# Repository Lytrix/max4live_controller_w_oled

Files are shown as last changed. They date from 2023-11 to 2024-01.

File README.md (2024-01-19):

# Max4Live Magnetic Encoder controller with oled screen 

This repository contain the files to be able to create a Max4live 4 controller with Oled as a 5HP Eurorack module to control your VST plugins.

This setup can easily be extended to a 4 units by using jumper cables on the same pcb together with the headers on the boards to maximize a 5 panel order from jlcpcb.

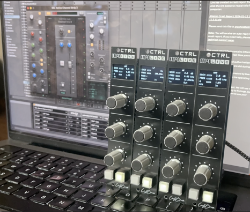
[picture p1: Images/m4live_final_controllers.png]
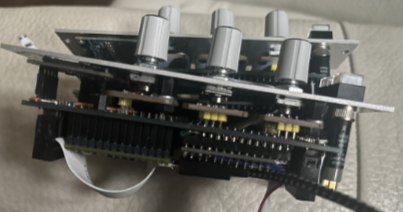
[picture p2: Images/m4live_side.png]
 

### How to install & use ###

1. Download this repo
2. Open the Arduino code and upload to the Teensy
3. Copy the `Max4Live Controller & Hub` folder to `/Music/Ableton/User Library/Presets/Audio Effects`
4. Open Ableton and place the `Max4live Serial Hub OSC.amxd` to the master channel and select your Teensy device.
5. Place `Max4live Controller OSC.amxd` on to the track you want to control
6. Select the VST device in the pull down menu which you want to control
7. Select the parameters for each potentiometer and button row.

### History ###

After using excelent Eurorack Droid system and having created my own Launchpad type solution on it, I wanted to have more hands on controllers also for my VST plugins within Ableton.

I really like the SSL suite of EQ's so I first looked at the UC1, As it was too big to fit in my small studio, I decided to build my own eurorack version to fit into my controller case with visual feedback to limit having to look at the DAW screen when adjusting EQ. 

#### MIDI? ####
I discovered early on the 127 midi steps were not fine grained enough.
Even using the pitchbend range or using MSB/LSB (sending on CC1 + CC 32) were often with issues still:
1. Still quite noisy with an analog encoder so hard to dail in precise values
2. Ableton could not set a parameter as 14bit midi 

So after some experimentation I decided to go with using an 3 euro AS5600 magnetic encoder and a cheap 0.75 Euro EC11 encoder to get a noise free 12bit 4096 step resolution which was precise enough to dail precise frequencies using this video as an example:
https://www.youtube.com/watch?v=1UmqNF65rck

This worked surpisingly well and is a great hack!

#### Breadboard tests and hacking the potentiometer to work with the magnetic encoder ####

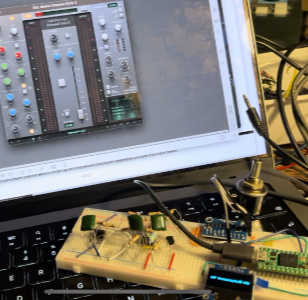
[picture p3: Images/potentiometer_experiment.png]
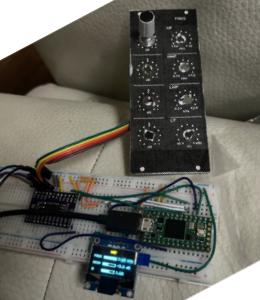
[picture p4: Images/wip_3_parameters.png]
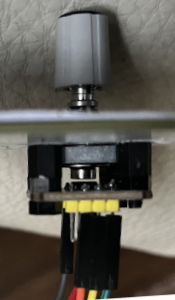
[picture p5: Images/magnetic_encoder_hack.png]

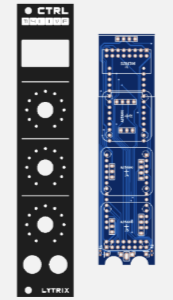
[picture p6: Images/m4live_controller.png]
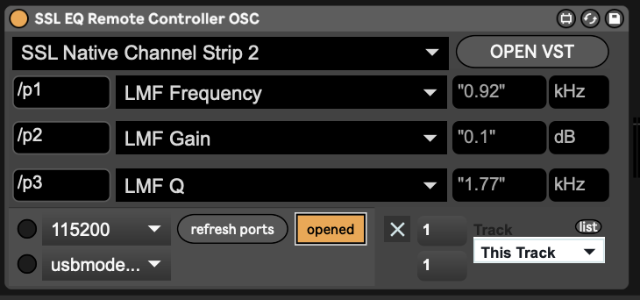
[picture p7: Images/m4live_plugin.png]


#### SYNC mouse and controller input ####
The next challenge was to ensure the encoder did not switch back to 0 halfway if the parameter changed via mouse input or when the parameter type changed. 
The solution was to set the offset of the magnetic encoder chip when the value changed externally. That way the encoder is always in sync before it adjusts it's value.

I coded a piece of logic to ensure whenever the value of the encoder is outside of +-2 numbers, MaxMSP sends an offset value update to the Teensy. 
The encoder is only allowed to change the values when the values of the VST parameter and the AS5600 offset are the same.

Th next challenge was to ensure the value was updated before the encoder could output any values. Here I got a lot of race condition issues, and it took me a week before I could tackle this. 

#### Controller & Display updates ####
For all functions I use lists to iterate over all changed values which are updated and also to set each of the AS5600 controllers and OSC adresses within different functions. This makes the code more DRY and makes it easier to add more parameters.

I created one function to gather all values to be displayed which loops in the main loop of the Arduino code.
I also created one function to set all updates from the encoders
And created one function to parse to each specific OSC address recieving part. 

### Parts list ###
- 1 Teensy 4.0 with headers
- 4-16 [AS5600 magnetic angle sensors](https://www.tinytronics.nl/shop/en/sensors/magnetic-field/as5600-magnetic-angle-sensor-encoder-module)
- 4-16 [EC11 rotary encoders](https://www.tinytronics.nl/shop/en/switches/manual-switches/rotary-encoders/rotary-encoder-ec11-20mm)
- 1-4 [25mm wide SSD1306 Oled Screens](https://www.ebay.com/itm/145136236774), or [Gadgetbouw.nl](https://www.gadgetbouw.nl/shop/0-96inch-128x64-i2c-oled-scherm-ssd1306-wit-of-blauw/) Check if they are really 25mm in width visible by the mounting holes being directly to the end of the pcb on both sides. Most cheap SSD1306 Oleds are 27mm.
- 1-5 PCB boards from jlcpcb
- 1-5 Alu front panels from jlcpcb
- Header pins and sockets
- [M3 nylon spacers 6mm](https://www.amazon.nl/dp/B07CG7F2YL?psc=1&ref=ppx_yo2ov_dt_b_product_details)
- [M3 nylon nuts](https://www.amazon.nl/dp/B07CG4C5QY?psc=1&ref=ppx_yo2ov_dt_b_product_details)
- 1 Superglue for mounting magnets and spacers
- 2-8 pushbuttons [EAO](https://www.techniekwebshop.nl/eao-benelux-serie-19-drukknop-9x9-puls-1m-verlicht-verkoop-per-1-x-1-stuk-19-451-035-7011339-type-knop-hoog-kleur-knop-zonder-toetsenp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) or cheaper 9.2mm types from [Ebay](https://www.ebay.com/itm/154221529860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) 

## Software ##

The software side consists on 2 pieces of code. One for the Teensy and one for Max4live.

I tested first a simple setup with using the standard serial ASCII communication, but found it quite fiddly to ensure to retrieve each different piece of information being send.
The [Open Sound Control (OSC)](https://opensoundcontrol.stanford.edu/spec-1_0.html) addressing structure felt like a much more robust way to send information back and forth, but unfortunately the OSC library from [CNMAT](https://github.com/CNMAT/OSC) did not work properly any more in the current MaxMSP and via serial (instead of network port). After a lot of research I finally found a good working library to make this work on the Teensy with MaxMSP (jey!):
https://github.com/thomasfredericks/MicroOsc

### Research documentation ###

Max4Live using more than 1 instance fix: add r --- to create random unique numbers
https://cycling74.com/forums/multiple-max4live-instances

Serial input Teensy to MaxMSP
https://www.youtube.com/watch?v=6bT3G4Mep7E

Serial output MaxMSP to Teensy
https://www.youtube.com/watch?v=68L-WHh3Ows

Button switch using internal pull up:
https://www.pjrc.com/teensy/td_digital.html  

MaxMSP scaling log
https://cycling74.com/forums/vst-plugin-parameter-scaling-problem

Dynamically load bpatchers:
https://cycling74.com/forums/dynamically-created-sub-patchersbpatches

Dummy virtual Serial
https://arduino.stackexchange.com/questions/9857/can-i-make-the-arduino-ignore-serial-print

Best example with many displays
https://www.youtube.com/watch?v=XFh9ZhL0jhE

Control Surface library struggle
https://github.com/tttapa/Control-Surface/issues/286

Good example to start with, also using 4 displays and using MCU:
https://projecthub.arduino.cc/criusdigitalstudio/diy-usb-midi-daw-controller-ecdcf6

good example of display fader
https://github.com/yilmazyurdakul/ArduinoOledMidiController
https://github.com/yilmazyurdakul/ArduinoOledMidiController/blob/main/ArduinoFile.ino

4 rotary encoders with midi control
http://little-scale.blogspot.com/2017/04/teensy-36-basicsusing-rotary-encoders.html

2 displays
https://www.brainy-bits.com/post/two-is-better-than-one-how-to-connect-two-spi-oled-displays

4 displays with Arduino
https://www.youtube.com/watch?v=MO6hbQcX8fE

4 displays and 4 encoders with visuals
https://projecthub.arduino.cc/yilmazyurdakul/arduino-midi-controller-with-encoder-oled-display-eeprom-311960

### Libraries ###
display https://www.pjrc.com/teensy/td_libs_SSD1306.html
encoder https://www.pjrc.com/teensy/td_libs_Encoder.html
endless potentiometer: https://github.com/juanlittledevil/EndlessPotentiometer
noise reducer analog signal: https://github.com/dxinteractive/ResponsiveAnalogRead

scroll text example:
https://stackoverflow.com/questions/40564050/scroll-long-text-on-oled-display

midi https://github.com/tttapa/Control-Surface

## LCD suggestions ###
http://midibox.org/forums/topic/29225-modul-box-ng-v2/?do=findComment&comment=199453

Oled display <25mm height
https://www.winstar.com.tw/products/oled-module/graphic-oled-display/sh1106-oled.html

multiplexer met tutorial (zie ook youtube filmpje)
https://www.tinytronics.nl/shop/nl/communicatie-en-signalen/io-converters/i2c-multiplexer-tca9548a

128 pulse encoder (too expensive)
https://nl.mouser.com/datasheet/2/54/ace-777357.pdf

1024 to 256 midi values with 10 bit nano:
https://forum.arduino.cc/t/potentiometer-send-midi-cc/142766/7

analog potentiometer Kore2:
https://hackaday.io/project/171841-driveralgorithm-for-360-deg-endless-potentiometer
with: https://nl.mouser.com/ProductDetail/Alpha-Taiwan/RV112FF-40B3N22F0B10K?qs=Znm5pLBrcAJwOGngbhkPgg%3D%3D

more examples:
https://diyelectromusic.wordpress.com/2021/09/28/arduino-midi-rotary-encoder-controller/

magnetic encoder:
https://curiousscientist.tech/blog/as5600-magnetic-position-encoder

working magnetic encoder example
https://www.youtube.com/watch?v=1UmqNF65rck

Bourns dail 20 turn
https://www.zendamateur-marktplaats.nl/componenten/componenten-anders/bourns-dial-model-h-46-36496.html

potential bigger potentiometer:
https://www.gear4music.com/Guitar-and-Bass/Emerson-Custom-CTS-250K-Short-Split-Shaft-Pro-Potentiometer/1GAA

Encoder example fast/slow relative unsigned bit:
https://remotify.io/community/question/absolute-14-bit

OSC
https://github.com/CNMAT/OSC/blob/master/examples/SerialOscuinowithMessages/SerialOscuinowithMessages.ino
https://www.ableton.com/en/packs/connection-kit/
https://github.com/thomasfredericks/MicroOsc

https://forum.arduino.cc/t/slipserial-and-osc-but-generally-reading-serial-across-loop-s/563369

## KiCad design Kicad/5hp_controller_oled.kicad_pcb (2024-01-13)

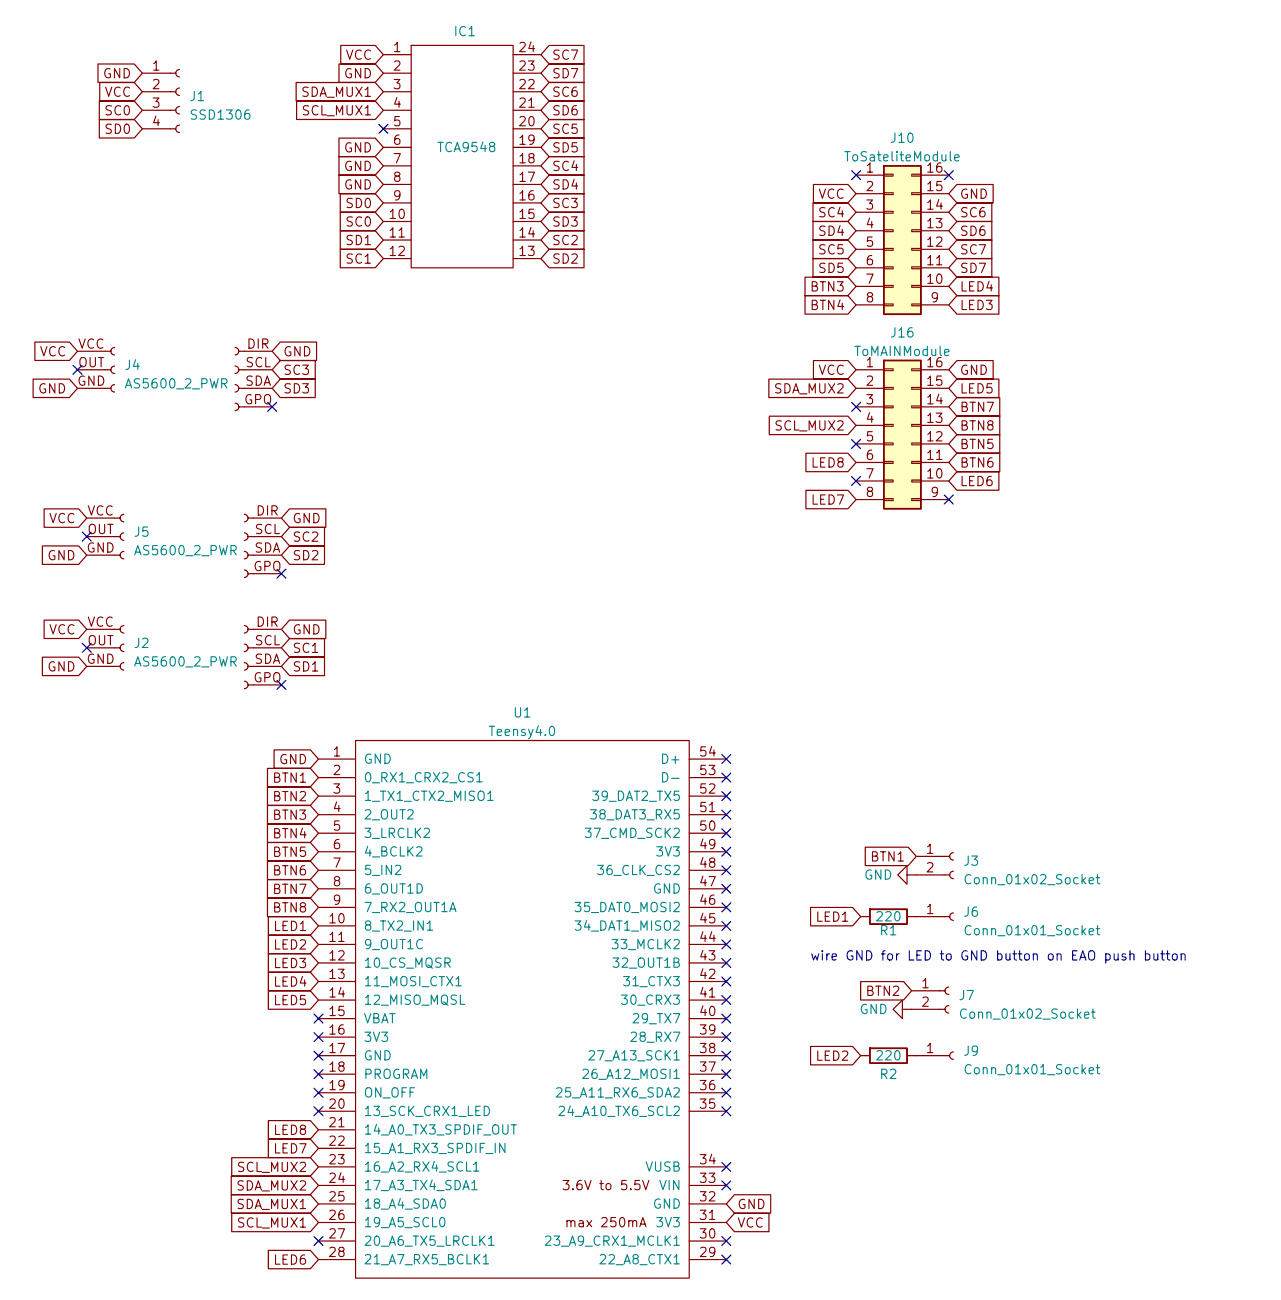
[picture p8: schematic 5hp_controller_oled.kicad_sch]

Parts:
IC1: TCA9548; DIP-24_W9.xx mm_Socket
J1: SSD1306; 128x64OLED_25mm
J2, J4, J5: AS5600_2_PWR; AS5600
J3, J7: Conn_01x02_Socket; PinHeader_1x02_P2.54mm_Vertical
J6, J9: Conn_01x01_Socket; PinHeader_1x01_P2.54mm_Vertical
J10: ToSateliteModule; PinSocket_2x08_P2.54mm_Vertical
J16: ToMAINModule; PinSocket_2x08_P2.54mm_Vertical
R1, R2: 220; R_0603_1608Metric_Pad0.98x0.95mm_HandSolder
U1: Teensy4.0; Teensy40_SMT

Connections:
BTN1: J3.1, U1.2 (0_RX1_CRX2_CS1)
BTN2: J7.1, U1.3 (1_TX1_CTX2_MISO1)
BTN3: J10.7, U1.4 (2_OUT2)
BTN4: J10.8, U1.5 (3_LRCLK2)
BTN5: J16.12, U1.6 (4_BCLK2)
BTN6: J16.11, U1.7 (5_IN2)
BTN7: J16.14, U1.8 (6_OUT1D)
BTN8: J16.13, U1.9 (7_RX2_OUT1A)
GND: IC1.2 (GND), IC1.6 (A0), IC1.7 (A1), IC1.8 (A2), J1.1, J2.DIR (Pin_4), J2.GND (Pin_3), J3.2, J4.DIR (Pin_4), J4.GND (Pin_3), J5.DIR (Pin_4), J5.GND (Pin_3), J7.2, J10.15, J16.16, U1.1 (GND), U1.32 (GND)
LED1: R1.2, U1.10 (8_TX2_IN1)
LED2: R2.2, U1.11 (9_OUT1C)
LED3: J10.9, U1.12 (10_CS_MQSR)
LED4: J10.10, U1.13 (11_MOSI_CTX1)
LED5: J16.15, U1.14 (12_MISO_MQSL)
LED6: J16.10, U1.28 (21_A7_RX5_BCLK1)
LED7: J16.8, U1.22 (15_A1_RX3_SPDIF_IN)
LED8: J16.6, U1.21 (14_A0_TX3_SPDIF_OUT)
unnamed: J6.1, R1.1
unnamed: J9.1, R2.1
SC0: IC1.10 (SC0), J1.3
SC1: IC1.12 (SC1), J2.SCL (Pin_5)
SC2: IC1.14 (SC2), J5.SCL (Pin_5)
SC3: IC1.16 (SC3), J4.SCL (Pin_5)
SC4: IC1.18 (SC4), J10.3
SC5: IC1.20 (SC5), J10.5
SC6: IC1.22 (SC6), J10.14
SC7: IC1.24 (SC7), J10.12
SCL_MUX1: IC1.4 (SCL), U1.26 (19_A5_SCL0)
SCL_MUX2: J16.4, U1.23 (16_A2_RX4_SCL1)
SD0: IC1.9 (SD0), J1.4
SD1: IC1.11 (SD1), J2.SDA (Pin_6)
SD2: IC1.13 (SD2), J5.SDA (Pin_6)
SD3: IC1.15 (SD3), J4.SDA (Pin_6)
SD4: IC1.17 (SD4), J10.4
SD5: IC1.19 (SD5), J10.6
SD6: IC1.21 (SD6), J10.13
SD7: IC1.23 (SD7), J10.11
SDA_MUX1: IC1.3 (SDA), U1.25 (18_A4_SDA0)
SDA_MUX2: J16.2, U1.24 (17_A3_TX4_SDA1)
VCC: IC1.1 (VCC), J1.2, J2.VCC (Pin_1), J4.VCC (Pin_1), J5.VCC (Pin_1), J10.2, J16.1, U1.31 (3V3)

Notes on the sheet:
wire GND for LED to GND button on EAO push button

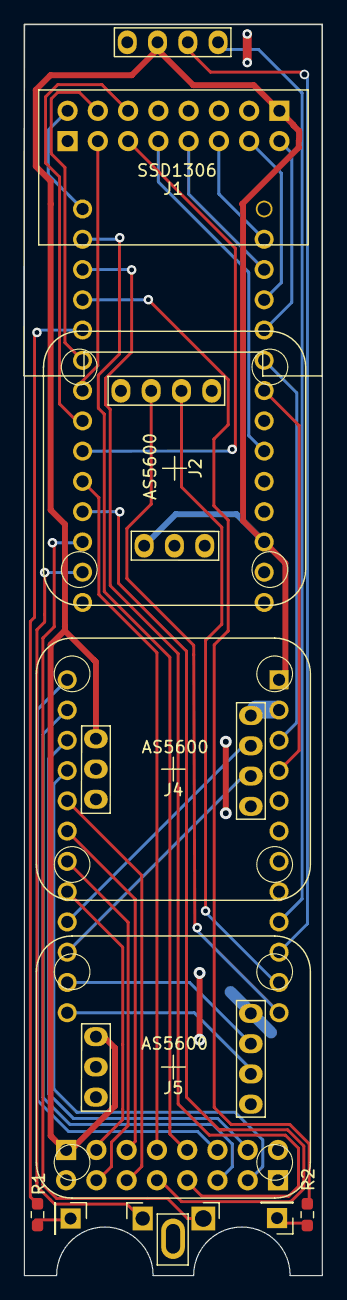
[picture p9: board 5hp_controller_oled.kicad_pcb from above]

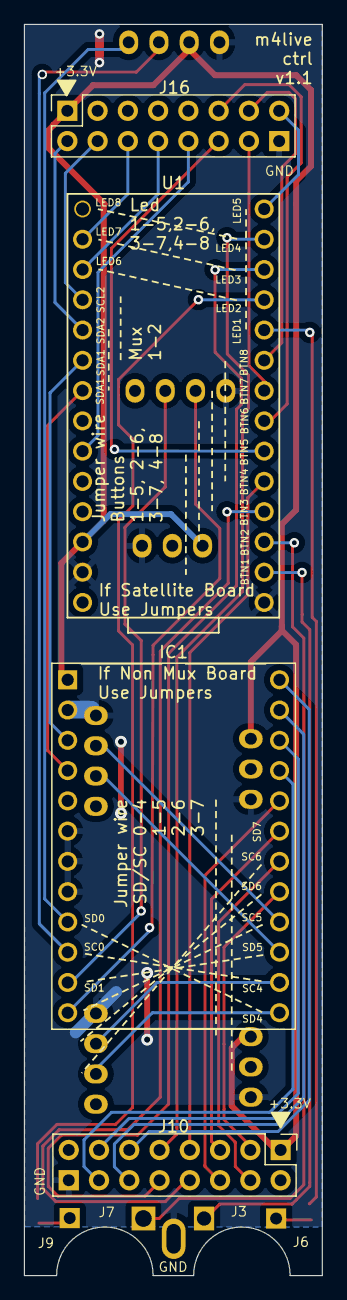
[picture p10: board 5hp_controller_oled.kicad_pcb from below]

Board: 2 copper layers, 25.0 x 105.0 mm, 14 parts (4 on the bottom side), 40 nets.

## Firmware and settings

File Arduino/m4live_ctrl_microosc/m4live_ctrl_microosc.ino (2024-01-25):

#include <Wire.h>
#include <AS5600.h>
#include <MicroOscSlip.h>
#include <Adafruit_GFX.h>
#include <Adafruit_SSD1306.h>

// #include "ADS1X15.h"
// #include "MIDIUSB.h"
// #include <Smoothed.h>

// THE NUMBER 128 BETWEEN THE < > SYMBOLS  BELOW IS THE MAXIMUM NUMBER OF BYTES RESERVED FOR INCOMMING MESSAGES.
// MAKE SURE THIS NUMBER OF BYTES CAN HOLD THE SIZE OF THE MESSAGE YOUR ARE RECEIVING IN ARDUINO.
// OUTGOING MESSAGES ARE WRITTEN DIRECTLY TO THE OUTPUT AND DO NOT NEED ANY RESERVED BYTES.
MicroOscSlip<1024> myMicroOsc(&Serial);  // CREATE AN INSTANCE OF MicroOsc FOR SLIP MESSAGES

unsigned long myChronoStart = 0;  // VARIABLE USED TO LIMIT THE SPEED OF THE loop() FUNCTION.
unsigned long timeCnt = 0;
const long SCREEN_TIMEOUT = 60000;

// Set address of first and second I2C multiplexer
#define TCAADDR 0x70

// Create instance for Magnetic Readers ctrl module 1 first i2c
AS5600 as5600_0(&Wire);
AS5600 as5600_1(&Wire);
AS5600 as5600_2(&Wire);
// Create instance for Magnetic Readers ctrl module 2 first i2c
AS5600 as5600_3(&Wire);
AS5600 as5600_4(&Wire);
AS5600 as5600_5(&Wire);
// Create instance for Magnetic Readers ctrl module 3 second i2c
AS5600 as5600_6(&Wire1);
AS5600 as5600_7(&Wire1);
AS5600 as5600_8(&Wire1);
// Create instance for Magnetic Readers ctrl module 4 second i2c
AS5600 as5600_9(&Wire1);
AS5600 as5600_10(&Wire1);
AS5600 as5600_11(&Wire1);

// Reference list of classes Used to iterate over in the OSC address offset
AS5600 *as5600List[4][3]= {
  {&as5600_0, &as5600_1, &as5600_2},
  {&as5600_3, &as5600_4, &as5600_5},
  {&as5600_6, &as5600_7, &as5600_8},
  {&as5600_9, &as5600_10, &as5600_11}
}; 

// List of Multiplexer wire and channel number for each magnetic encoder
unsigned int tcaAddress[4][3][2] = {
    {
      {0,1},
      {0,6},
      {0,0}
    }, // main controller, 7 is oled
    {
      {0,3},
      {0,4},
      {0,5}
    },  // satellite controller, 2 is oled
    {
      {1,1},
      {1,6},
      {1,7}
    },  // satellite controller with tca multiplexer, 0 is oled
    {
      {1,3},
      {1,4},
      {1,5}
    }   // satellite controller with tca multiplexer, 2 is oled
};

// Encoder direction per controller, per magnetic encoder. 1 is clockwise, 0 is counterclockwise
unsigned int as5600_rotation[4][3];

// Store invert button 1 or 0 for each button
unsigned int invertButton[4][2];

// List of Multiplexer wire and channel number for each display
unsigned int tcaDisplayAddress[4][2] = {
  {0, 7},
  {0, 2}, // ctrl1, ctrl2 on wire (=0)
  {1, 0},
  {1, 2}  // ctrl3, ctrl4 on wire1 (=1)
};  

// Set Display information
#define SCREEN_ADDRESS 0x3C  ///< See datasheet for Address; 0x3D for 128x64, 0x3C for 128x32
#define SCREEN_WIDTH 128
#define SCREEN_HEIGHT 64
#define OLED_RESET -1
#define I2C_SPEED 400000
#define I2C_BUSS1 &Wire  
#define I2C_BUSS2 &Wire1

// Create an instance for each display for each hardware i2c
Adafruit_SSD1306 display1_2(SCREEN_WIDTH, SCREEN_HEIGHT, I2C_BUSS1, OLED_RESET, I2C_SPEED);
Adafruit_SSD1306 display3_4(SCREEN_WIDTH, SCREEN_HEIGHT, I2C_BUSS2, OLED_RESET, I2C_SPEED);

// Reference list of classes Used to iterate over in the OSC address offset
Adafruit_SSD1306 *displayList[4]= {
  &display1_2, &display1_2,   //wire
  &display3_4, &display3_4    //wire1
}; 

// Analog Potentiometer reader 16 bit:
// ADS1115 ADS(0x48);

// Set smoothing data type
// Smoothed <int16_t> mySensor;

// Setting for 14bit midi CC
// #define LOWCC1 1
// #define HIGHCC1 LOWCC1 + 32


/***********************
     Set Variables
************************/

const char initialDisplay[4][5] = {
  "MAX",
  "4",
  "LIVE",
  "CTRL"
};

const char oscPotentiometerAddress[4][3][9] = {
   {
    "/c/1/p/1", 
    "/c/1/p/2", 
    "/c/1/p/3"
  },
  {
    "/c/2/p/1", 
    "/c/2/p/2", 
    "/c/2/p/3"
  },
  {
    "/c/3/p/1", 
    "/c/3/p/2", 
    "/c/3/p/3"
  },
  {
    "/c/4/p/1", 
    "/c/4/p/2", 
    "/c/4/p/3"
  }
};

const char oscAddressButton[4][3][9]= {
  {
    "/c/1/b/1",
    "/c/1/b/2"
  },
  {
    "/c/2/b/1",
    "/c/2/b/2"
  },
  {
    "/c/3/b/1",
    "/c/3/b/2"
  },
  {
    "/c/4/b/1",
    "/c/4/b/2"
  }
};

// Lists of parameter values to store OSC message values as a buffer for storing and taking display values from.
volatile char displayTxtKnob[4][3][3][12];

// List of titles for each controller
volatile char displayTxtController[4][16];

// List of display values for each button
volatile char displayTxtButton[4][2][12];

// List for storing each received OSC message for setting the slider width
volatile float sliderValue[4][3];

// For creating OSC address to receive on
// char oscAddress[24];
// char oscParam[3][4] = {"/c", "/p", "/b"}; // controller, potentiometer, button
// char strDeviceNumber[3];
// char strParamNumber[3];

// Store old and new send value for each TCA channel in a list to reduce number of serial sends
unsigned int lastEncoderValue[4][3];

// Setup default display cursor positions to loop in updateDisplay function.
unsigned int displayPos[3][3][2] = {
  { // display row 2
    {2, 12},
    {75,12},
    {105,12}
  },
  { // display row 3
    {2, 27},
    {75,27},
    {105,27}
  },
  { // display row 4
    {2, 42},
    {75,42},
    {105,42}
  }
};

// Button and led pin numbers per ctrl module 
const unsigned int buttonPin[4][2] = {
  {0, 1},
  {2, 3},
  {4, 5},
  {6, 7}
};

const unsigned int ledPin[4][2] = {
  {8, 9},
  {10, 11},
  {12, 15},
  {14, 21}  // rewired pin 13 to 21 due to also turning reset led on on teensy board when used
};

// Led, buttonstate variables
float ledState[4][2];
unsigned int lastButtonState[4][2];
unsigned int currentButtonState[4][2];


// Test variables
// int ledPinTeensy = 13;
// int analogPin = A0;  // potentiometer wiper (middle terminal) connected to analog pin 3
// int val = 0;         // variable to store the value read
// int pitch;


/***********************
  Functions
************************/

// Channel and Wire select on each Multiplexer via tcaAddress array
void tcaSelect(unsigned int tcaAddress[2]) {
  unsigned int wire = tcaAddress[0];
  unsigned int channel = tcaAddress[1];

  // if (channel > 7) return;
  if (wire == 0) {
    Wire.beginTransmission(TCAADDR);
    Wire.write(1 << channel);
    Wire.endTransmission();
  }
  if (wire == 1) {
    Wire1.beginTransmission(TCAADDR);
    Wire1.write(1 << channel);
    Wire1.endTransmission();
  }
}
// Send OSC message when moving potentiometer for each AS5600 magnetic encoder
void sendValueMagneticEncoder(const char *oscAddress, AS5600 &as5600_reference, unsigned int lastEncoderValue, unsigned int tcaAddress) {
  tcaSelect(tcaAddress);
  int currentEncoderValue = as5600_reference.readAngle();

  if (currentEncoderValue != lastEncoderValue) {  
      myMicroOsc.sendInt(oscAddress, currentEncoderValue);  // SEND MAGNETIC ENCODE
      lastEncoderValue = currentEncoderValue;
  }
}

// Offset Magnetic Encoder // If VST value is update via mouse input, recieve updated value to calculate new offset of magnetic encoder, so it does not jump.
void setOffsetMagneticEncoder(unsigned int deviceNumber, AS5600 &as5600_reference, unsigned int channel, unsigned int parameterOffset, unsigned int tcaAddress, unsigned int lastEncoderValue) {
  const char *oscAddress = oscPotentiometerAddress[deviceNumber][channel];

  tcaSelect(tcaAddress);
  unsigned int readAngle = as5600_reference.readAngle();
  // Serial.print("instance");
  // Serial.println(readAngle);
  // Serial.print("parameterOffset");
  // Serial.println(parameterOffset);
  if (readAngle != parameterOffset) {
    float previous_difference = as5600_reference.getOffset();
    float new_difference = (((float(parameterOffset) - float(readAngle)) / 4096.) * 360.) + previous_difference;
    if (new_difference > 360.) {
      new_difference = new_difference - 360.;
    }
    if (new_difference < -360.) {
      new_difference = new_difference + 360.;
    }
    as5600_reference.setOffset(new_difference);

    // to do: fix the code below as existing void. it currenty hangs if I put it in.
    // char *oscName = "/p"; 
    unsigned int currentEncoderValue = as5600_reference.readAngle();
    if (currentEncoderValue != lastEncoderValue) {
      myMicroOsc.sendInt(oscAddress, currentEncoderValue);  // SEND MAGNETIC ENCODE
      lastEncoderValue = currentEncoderValue;
    }
  }
}

// // Parse all OSC addresses in a for loop by (1, "/name") equals: /param1/name
// void oscAddressParser(char oscDeviceName[4], int deviceNumber, char oscParamName[4], int parameterNumber, char oscAddressType[10]){
//   sprintf(strDeviceNumber, "/%d", deviceNumber+1);   // /1, /2, ...
//   sprintf(strParamNumber, "/%d", parameterNumber+1); // /1, /2, ...
 
//   strcpy(oscAddress, oscDeviceName);   // /c
//   strcat(oscAddress, strDeviceNumber); // /1
//   strcat(oscAddress, oscParamName);    // /p
//   strcat(oscAddress, strParamNumber);  // /1
//   strcat(oscAddress, oscAddressType);  // /value
//   // Serial.print("created OSCadress: ");
//   // Serial.println(oscAddress); // /c1/p1/value
// }

// OSC MESSAGE LISTENER
void myOnOscMessageReceived(MicroOscMessage& oscMessage) {
  
  // Recieve the main title for each controller 
  // No display update need, because update display is triggered by /name when selecting potentiometer 1
  // For example /title 1 2 "LMF"
  if (oscMessage.checkOscAddressAndTypeTags("/title", "is")) {  
    unsigned int ctrl = oscMessage.nextAsInt() -1;
    strcpy(displayTxtController[ctrl], oscMessage.nextAsString()); 
  } else 

  // Receive the selected 4 chars parameter name for each controller (1,2,3,4) and potentiometer (1,2,3)
  // Along with corresponding unit names, optionally with the set inverse of potentiometer
  // For example: /value 1 2 "FREQ" "kHz" 0
  if (oscMessage.checkOscAddressAndTypeTags("/name", "iissi")) { 

    unsigned int ctrl = oscMessage.nextAsInt() -1;
    unsigned int pot = oscMessage.nextAsInt() -1;
    char *name = oscMessage.nextAsString();
    char *units = oscMessage.nextAsString();
    unsigned int invert = oscMessage.nextAsInt(); 

    // copy values to display buffer
    strcpy(displayTxtKnob[ctrl][pot][0], name); 
    strcpy(displayTxtKnob[ctrl][pot][2], units);
      
    if (invert == 0) {  // 0 or 1 to inverse potentiometer direction
      as5600List[ctrl][pot][0].setDirection(AS5600_CLOCK_WISE);
    } else {
      as5600List[ctrl][pot][0].setDirection(AS5600_COUNTERCLOCK_WISE);
    }
    updateDisplay(displayList[ctrl][0], ctrl, tcaDisplayAddress[ctrl]); 
  } else
  
  // Receive string value and float to display real world value
  // and the 0-1 float value to set the slider width 
  // For example: /value 1 2 "12.0" 0.860321
  if (oscMessage.checkOscAddressAndTypeTags("/value", "iisf")) { 
    unsigned int ctrl = oscMessage.nextAsInt() -1;
    unsigned int pot = oscMessage.nextAsInt() -1;
    char *value = oscMessage.nextAsString();
    float slider = oscMessage.nextAsFloat();

    if (displayTxtKnob[ctrl][pot][1] != value) {
      strcpy(displayTxtKnob[ctrl][pot][1], value); // "12.0"
      timeCnt = millis();                          // Reset time for screensaver 
    } 
    sliderValue[ctrl][pot] = slider;               // 0.12345
    updateDisplay(displayList[ctrl][0], ctrl, tcaDisplayAddress[ctrl]);
  } else 
  
  // Sync encoder value to VST value by receiving VST value as new offset value as 0-4096 int
  // It will offset the encoder to the new value if the current value is less or more then 5 out of range.
  // For example: /offset 1 2 4096"
  if (oscMessage.checkOscAddressAndTypeTags("/offset", "iii")) { 
    unsigned int ctrl = oscMessage.nextAsInt() -1;
    unsigned int pot = oscMessage.nextAsInt() -1;
    unsigned int parameterOffset = oscMessage.nextAsInt();
    setOffsetMagneticEncoder(ctrl, as5600List[ctrl][pot][0], pot, parameterOffset, tcaAddress[ctrl][pot], lastEncoderValue[ctrl][pot]); // cntr 1, channel 0, offset 4096, instance as5600_0
  } else
  
  // Receive VST button state to set led state AND set led on/off
  // it uses floats as states to also cater for continuous values > or < 0.5
  // For example: /button 1 2 0. "Off"
  if (oscMessage.checkOscAddressAndTypeTags("/button", "iisfi")) {  
    unsigned int ctrl = oscMessage.nextAsInt() -1;
    unsigned int pot = oscMessage.nextAsInt() -1;
    const char *buttonValue = oscMessage.nextAsString();
    float state = oscMessage.nextAsFloat(); // 1. or 0.
    invertButton[ctrl][pot] = oscMessage.nextAsInt();

    strcpy(displayTxtButton[ctrl][pot], buttonValue);  // "IN" 
    updateDisplay(displayList[ctrl][0], ctrl, tcaDisplayAddress[ctrl]);
    timeCnt = millis(); // reset time for screensaver
    
    if (invertButton[ctrl][pot] == 1) {
      if (state > 0.5){
        digitalWrite(ledPin[ctrl][pot], LOW);
        ledState[ctrl][pot]=HIGH; 
      } else {
        digitalWrite(ledPin[ctrl][pot], HIGH);
        ledState[ctrl][pot]=LOW;
      }
    } else  {
      if (state > 0.5){
        digitalWrite(ledPin[ctrl][pot], HIGH);
        ledState[ctrl][pot]=HIGH;
      }  else {
        digitalWrite(ledPin[ctrl][pot], LOW);
        ledState[ctrl][pot]=LOW; 
      }  
    }
   
  }
 

  // Basic Test reset led on Teensy
  // if (oscMessage.checkOscAddressAndTypeTags("/led")) {  // IF THE ADDRESS IS /led
  //   int newValue = oscMessage.nextAsInt();   // GET NEW VALUE AS INT
  //   digitalWrite(ledPinTeensy, newValue);         // SET LED OUTPUT TO VALUE (DIGITAL: OFF/ON)
  //   Serial.write("led on");
  // }
}

int16_t sliderLength = 37;
int16_t sliderHeight = 5;
int16_t fillLength;

// Clear and push display with updated values in void Loop()
void updateDisplay(Adafruit_SSD1306 &display, unsigned int c, unsigned int tcaDisplayAddress[2]) {
    tcaSelect(tcaDisplayAddress);

    display.clearDisplay();
    display.setTextSize(1);  // Draw 1X-scale text
    display.setTextColor(SSD1306_WHITE);
    
    // Generate 1 of 3 rows of display information using the prefilled array.
    //for (int row = 0; row <= 2; row++) { // loop over each display row
      //for (int col = 0; col <= 2; col++) { // loop over each display element
  // Controller 1  
    // Row 1
      // Column 1: Name 
        const char *name1 = displayTxtKnob[c][0][0];
        display.setCursor(displayPos[0][0][0], displayPos[0][0][1]);
        display.println(name1);
      // Column 3: Value  
        const char *value1 = displayTxtKnob[c][0][1];
        display.setCursor(displayPos[0][1][0], displayPos[0][1][1]);
        display.println(value1);
      // Column 4: Units
        const char *units1 = displayTxtKnob[c][0][2];
        display.setCursor(displayPos[0][2][0], displayPos[0][2][1]);
        display.println(units1);
      // Column 2: Slider
        float slide1 = sliderValue[c][0];
        display.drawRect(33, displayPos[0][0][1]+2, slide1 * sliderLength, sliderHeight, SSD1306_WHITE);

    // Row 2
      // Column 1: Name  
       const char *name2 = displayTxtKnob[c][1][0];
        display.setCursor(displayPos[1][0][0], displayPos[1][0][1]);
        display.println(name2);
      // Column 3: Value  
        const char *value2 = displayTxtKnob[c][1][1];
        display.setCursor(displayPos[1][1][0], displayPos[1][1][1]);
        display.println(value2);
      // Column 4: Units
        const char *units2 = displayTxtKnob[c][1][2];
        display.setCursor(displayPos[1][2][0], displayPos[1][2][1]);
        display.println(units2);
      // Column 2: Slider
        float slide2 = sliderValue[c][1];
        display.drawRect(33, displayPos[1][0][1]+2, slide2 * sliderLength, sliderHeight, SSD1306_WHITE);

    // Row 3
      // Column 1: Name  
        const char *name3 = displayTxtKnob[c][2][0];
        display.setCursor(displayPos[2][0][0], displayPos[2][0][1]);
        display.println(name3);
      // Column 3: Value  
        const char *value3 = displayTxtKnob[c][2][1];
        display.setCursor(displayPos[2][1][0], displayPos[2][1][1]);
        display.println(value3);
      // Column 4: Units
        const char *units3 = displayTxtKnob[c][2][2];
        display.setCursor(displayPos[2][2][0], displayPos[2][2][1]);
        display.println(units3);
      // Column 2: Slider
        float slide3 = sliderValue[c][2];
        display.drawRect(33, displayPos[2][0][1]+2, slide3 * sliderLength, sliderHeight, SSD1306_WHITE);

    // Button 1 & 2 info
      const char *button1 = displayTxtButton[c][0];
      display.setCursor(2, 56);
      display.println(button1);
      
      const char *button2 = displayTxtButton[c][1];
      display.setCursor(75, 56);
      display.println(button2);
  
    // Variables for getTextBounds function to center text
    int16_t x1;
    int16_t y1;
    uint16_t width;
    uint16_t height;
    // center title text
    const char *title = displayTxtController[c];
    display.getTextBounds(title, 0, 0, &x1, &y1, &width, &height);
    display.setCursor((SCREEN_WIDTH - width) / 2, 0);
    display.println(title);
    
    display.display();
  }
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
void loop() {   
 

  myMicroOsc.onOscMessageReceived(myOnOscMessageReceived);  // TRIGGER OSC RECEPTION and updat Display if parameter value or button state is updated
  
  // Loop over as5600 instances and /pot1, /pot2, ...
  if (millis() - myChronoStart >= 50 && Serial.availableForWrite() > 20) {
    // Loop over ctrl 1,2,3,4
    // Loop over magnectic encoder 1,2,3
    sendValueMagneticEncoder("/c/1/p/1", as5600List[0][0][0], lastEncoderValue[0][0], tcaAddress[0][0]); 
    sendValueMagneticEncoder("/c/1/p/2", as5600List[0][1][0], lastEncoderValue[0][1], tcaAddress[0][1]);
    sendValueMagneticEncoder("/c/1/p/3", as5600List[0][2][0], lastEncoderValue[0][2], tcaAddress[0][2]);

    sendValueMagneticEncoder("/c/2/p/1", as5600List[1][0][0], lastEncoderValue[1][0], tcaAddress[1][0]);
    sendValueMagneticEncoder("/c/2/p/2", as5600List[1][1][0], lastEncoderValue[1][1], tcaAddress[1][1]);
    sendValueMagneticEncoder("/c/2/p/3", as5600List[1][2][0], lastEncoderValue[1][2], tcaAddress[1][2]);

    sendValueMagneticEncoder("/c/3/p/1", as5600List[2][0][0], lastEncoderValue[2][0], tcaAddress[2][0]);
    sendValueMagneticEncoder("/c/3/p/2", as5600List[2][1][0], lastEncoderValue[2][1], tcaAddress[2][1]);
    sendValueMagneticEncoder("/c/3/p/3", as5600List[2][2][0], lastEncoderValue[2][2], tcaAddress[2][2]);

    sendValueMagneticEncoder("/c/4/p/1", as5600List[3][0][0], lastEncoderValue[3][0], tcaAddress[3][0]);
    sendValueMagneticEncoder("/c/4/p/2", as5600List[3][1][0], lastEncoderValue[3][1], tcaAddress[3][1]);
    sendValueMagneticEncoder("/c/4/p/3", as5600List[3][2][0], lastEncoderValue[3][2], tcaAddress[3][2]);
    
    // loop over button 1, 2 for each controller
    buttonState("/c/1/b/1", 0, 0);
    buttonState("/c/1/b/2", 0, 1);

    buttonState("/c/2/b/1", 1, 0);
    buttonState("/c/2/b/2", 1, 1);
    
    buttonState("/c/3/b/1", 2, 0);
    buttonState("/c/3/b/2", 2, 1);
    
    buttonState("/c/4/b/1", 3, 0);
    buttonState("/c/4/b/2", 3, 1);

    myChronoStart = millis(); // update delay
  } 
  if (millis() > (timeCnt + SCREEN_TIMEOUT))
  {
    // Activate Screensaver
    tcaSelect(tcaDisplayAddress[0]);
    displayList[0][0].clearDisplay();
    displayList[0][0].display();
    
    tcaSelect(tcaDisplayAddress[1]);
    displayList[1][0].clearDisplay();
    displayList[1][0].display();
    
    tcaSelect(tcaDisplayAddress[2]);
    displayList[2][0].clearDisplay();
    displayList[2][0].display();
    
    tcaSelect(tcaDisplayAddress[3]);
    displayList[3][0].clearDisplay();
    displayList[3][0].display();
    
    digitalWrite(ledPin[0][0], LOW);
    digitalWrite(ledPin[0][1], LOW);
    digitalWrite(ledPin[1][0], LOW);
    digitalWrite(ledPin[1][1], LOW);
    digitalWrite(ledPin[2][0], LOW);
    digitalWrite(ledPin[2][1], LOW);
    digitalWrite(ledPin[3][0], LOW);
    digitalWrite(ledPin[3][1], LOW);
  }

  //Example send single osc message without loop
  //sendValueMagneticEncoder(as5600_0, 0, "/pot1");
  
  // Read a sensor value from analogue pin 0 of 16 bit ADC
  //int16_t raw = ADS.readADC(0);
  //Serial.println(raw);
  //mySensor.add(raw);

  // Output the smoothed sensor value to the serial
  //Serial.println(mySensor.get());
  
  //while (Serial.available()) {
  //  Serial.println(parameterName);
  
  // Convert incoming ASCI bytes to Strings and Monitor them.
  // String parameterValue = Serial.readStringUntil(10);
  // String parameterName = Serial.readStringUntil(10);
  // String parameterType = Serial.readStringUntil(10);
  //  delay(100);
  //  display.setCursor(0, 26);
  //  display.println(parameterName);
  //  display.setCursor(80, 26);
  //  display.println(String(parameterValue));
  //  display.setCursor(110, 26);
  //  display.println(String(parameterType));
  // display.display();
  //}
 
  //val = analogRead(analogPin);  // read the input pin
  //Serial.println(val);          // debug value

  // Serial.println(myPitchChange);
  // usbMIDI.sendPitchBend((raw -8192), 1);
  // delay(50);

  // usbMIDI.sendPitchBend((raw -8192), 2);
  // usbMIDI.read();
  // Serial.print("getData: ");
  // usbMIDI.getData2();
  // usbMIDI.PitchBend
  // usbMIDI.getType(6);
  // controlChange(0, HIGHCC1, raw << 2 & 0x7F);
  // controlChange(0, LOWCC1, (raw >> 7) & 0x7F);

  // Serial.print("Sending CC, value: ");
  // Serial.println(raw);
  // Serial.println();
  // MidiUSB.flush();
} // -- End of void Loop --

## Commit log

2023-11-24 Working 2 VSTs switching, using delay on pot send messages
2023-11-24 Added arduino teensy code
2023-11-29 Added kicad code and updated Readme
    [5hp_controller_oled-B_Cu.gbr, 5hp_controller_oled-B_Mask.gbr, 5hp_controller_oled-B_Paste.gbr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]
2023-11-29 images encoder
2023-11-29 Final pcb and frontpanel
    [5hp_controller_oled-B_Cu.gbr, 5hp_controller_oled-B_Mask.gbr, 5hp_controller_oled-B_Paste.gbr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]
2023-11-30 Added temp supports for screen opening to prevent crack during manufacturing
    [m4live_ctrl_frontpanel-B_Cu.gbr, m4live_ctrl_frontpanel-B_Mask.gbr, m4live_ctrl_frontpanel-B_Paste.gbr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]
2023-12-23 Reverted back to working Max4live version
    [12bitMagneticEncoder_ADC16bit1Pot_MidiCC_PB.ino]
2023-12-23 Set title caused isse, moved sliders to end with println
2023-12-23 Fixed Screen flickering, reverted back display setup
    [12bitMagneticEncoder_ADC16bit1Pot_MidiCC_PB.ino]
2023-12-23 fixed laggy display using 1M refresh
    [12bitMagneticEncoder_ADC16bit1Pot_MidiCC_PB.ino]
2023-12-26 Fully working patch, only led update from VST remains.
2023-12-27 Optimized led button behaviour
2024-01-02 Switch Track working again
2024-01-03 Select Track ID working, fixed hanging Max 8.5 v10
2024-01-09 Removed automatic opened and checklist menu from Serial as partial fix hanging Max.
    [12bitMagneticEncoder_ADC16bit1Pot_MidiCC_PB.ino]
2024-01-09 Reduced millis from 50>10 for sending serial faster to speed up display update
2024-01-12 Replaced serial logic with OSC CNMAT & test version OSC_tester (does recieve, does not send)
    [m4live_ctrl_microosc.ino]
2024-01-13 tweaked delay bangs, to update when track switches
2024-01-13 Fixed pcb errors (wrong footprint TCA, freed up pin 13)
    [5hp_controller_oled-B_Cu.gbr, 5hp_controller_oled-B_Mask.gbr, 5hp_controller_oled-B_Paste.gbr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]
2024-01-14 Switched to OSC message list and 1MHz oleds
2024-01-15 Set Global serial send/receive and optimised track switching
2024-01-15 Cleanup arduino code, changed order of controllers
2024-01-15 more cleanup, changes string to char strcpy button
2024-01-15 Fix refresh and center Title
    [m4live_ctrl_microosc.ino]
2024-01-15 cleanup arduino folders
2024-01-16 Fixed -1 parameter error button and added invert option button
    [m4live_ctrl_microosc.ino]
2024-01-16 Removed for loop in sending oscMessages from Arduino
2024-01-16 Buttonvalues now updating correctly when switching tracks in Ableton
    [m4live_ctrl_microosc.ino]
2024-01-16 Fixed wrong array as5600 numbers on controller 2
    [m4live_ctrl_microosc.ino]
2024-01-16 Fixed array iteration where -1 is used
    [m4live_ctrl_microosc.ino]
2024-01-16 removed for loop from updateDisplay() to fix wrongly updated sliders at initial update
    [m4live_ctrl_microosc.ino]
2024-01-16 Reverted back to stable version and c/1/p/1 instead of c/0/p/0
    [m4live_ctrl_microosc.ino]
2024-01-17 Fixed button updates on track switching
    [m4live_ctrl_microosc.ino]
2024-01-17 added extra track selected gate on input vst to ensure reducing hangups
2024-01-22 Finally properly restore state of device after opening song
2024-01-22 increase margins save button
2024-01-22 Switched to microosc Serial to work with Max 8.6.0
2024-01-23 Fixed wrong value override button setting when flipping A/B
2024-01-23 Fixed update slider value when switching A/B
2024-01-23 Fixed valus overridden by AB switch
2024-01-23 Use generated switch id instead of static number
2024-01-23 Read send value from button state to set AB switch
2024-01-23 Created separate Bpatcher for AB switch
2024-01-24 Added AB switch to 4K E & B
2024-01-24 store ab switch on 4kB
2024-01-24 Fixed closing gate on r-messages when switching B>A
2024-01-24 removed gate on track selected to update values on load
2024-01-25 Fixed missing -1 on on ctrl and param index
    [m4live_ctrl_microosc.ino]
2024-01-25 Fixed wrong osc addresses and . to ""
    [m4live_ctrl_microosc.ino]
2024-01-25 send bang to value on track change
2024-01-25 fixed hanging button state on Gate Fast Attack
2024-01-28 Fix regression non updating button values
2024-01-28 Load all settings by Sending reconnect to active track device after port is opened
2024-01-29 optimized AB-switch maxpat to be able to save again
2024-02-01 switch startup recieve
2024-02-01 increased polling selected track
2024-02-01 removed button parameter name, removed messages
2024-02-01 hotfix buttons
2024-02-02 removed delay on button switch fixing showing osc message on display
2024-02-02 reduced number of bangs to button OSC message
2024-02-03 reduced delay in value updates device m4live
